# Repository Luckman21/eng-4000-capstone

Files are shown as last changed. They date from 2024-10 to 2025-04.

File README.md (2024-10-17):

# ENG-4000-Capstone
Our repo for ENG 4000 F2024 - W2025.  This is where we will store project documents, code and other resources related to our team.

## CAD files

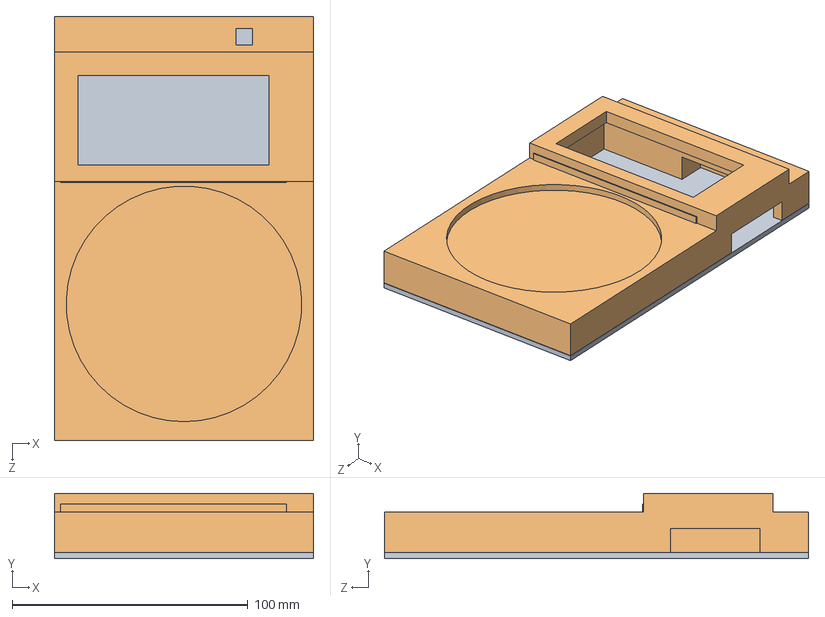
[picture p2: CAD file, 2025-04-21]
mech-design-team/Housings/Circuitry/CPSTN-A003 - ScaleHousing.SLDASM
110.0 x 27.7 x 180.0 mm
ScaleHousing
ScaleHousingLid

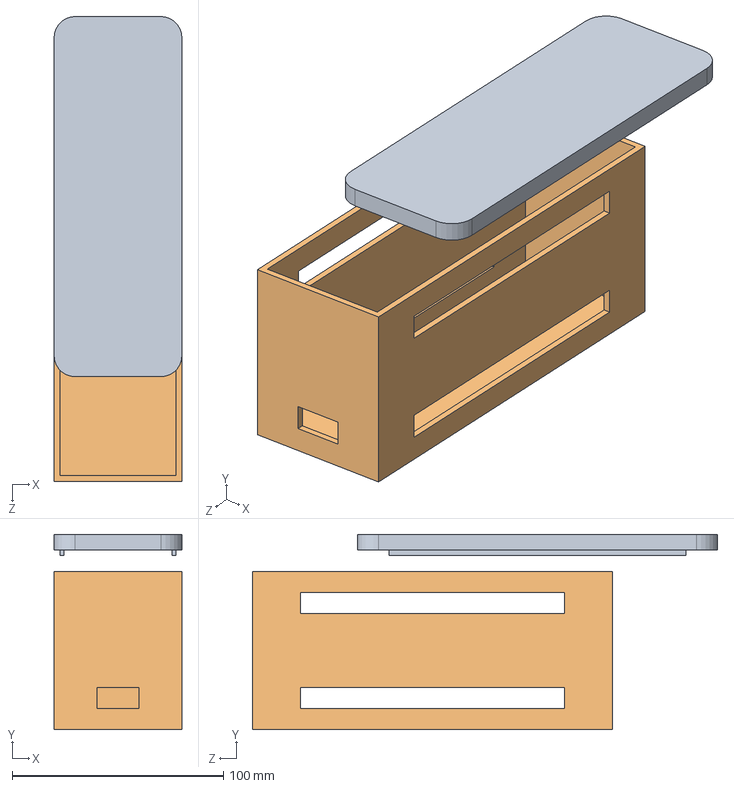
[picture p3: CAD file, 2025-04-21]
mech-design-team/Housings/Circuitry/CPSTN-A002 - Circuitry Housing.SLDASM
60.5 x 92.5 x 220.1 mm
BreadboardHousing
BreadboardHousingLid

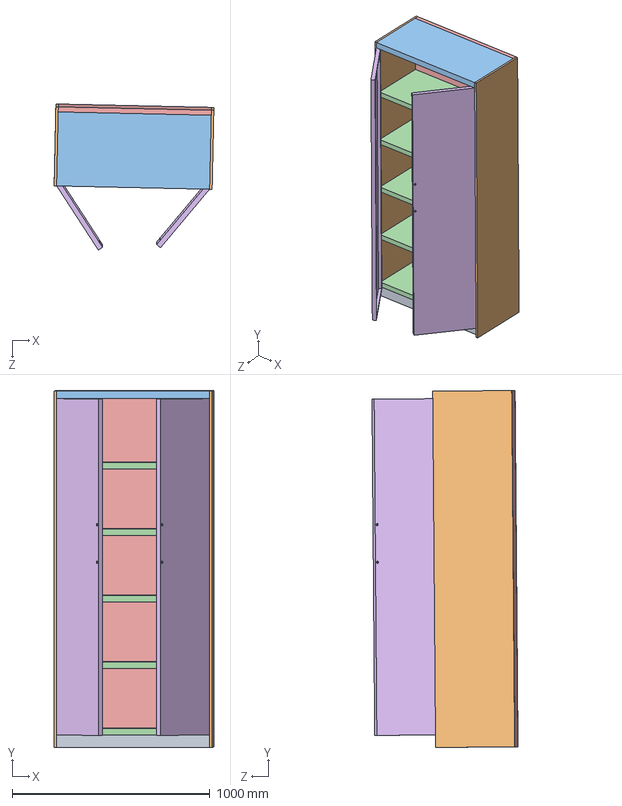
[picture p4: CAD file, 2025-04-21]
mech-design-team/Shelf/CPSTN-A001 - Shelving Unit Assembly.STEP
808.8 x 1806.6 x 739.3 mm
CPSTN-P001 - Shelf Base
CPSTN-P002 - Shelf Side Wall x 2
CPSTN-P003 - Shelf Roof
CPSTN-P004 - Cabinet Shelf x 5
CPSTN-P005 - Shelf Back Wall
CPSTN-P006 - Left Door
CPSTN-P007 - Right Door

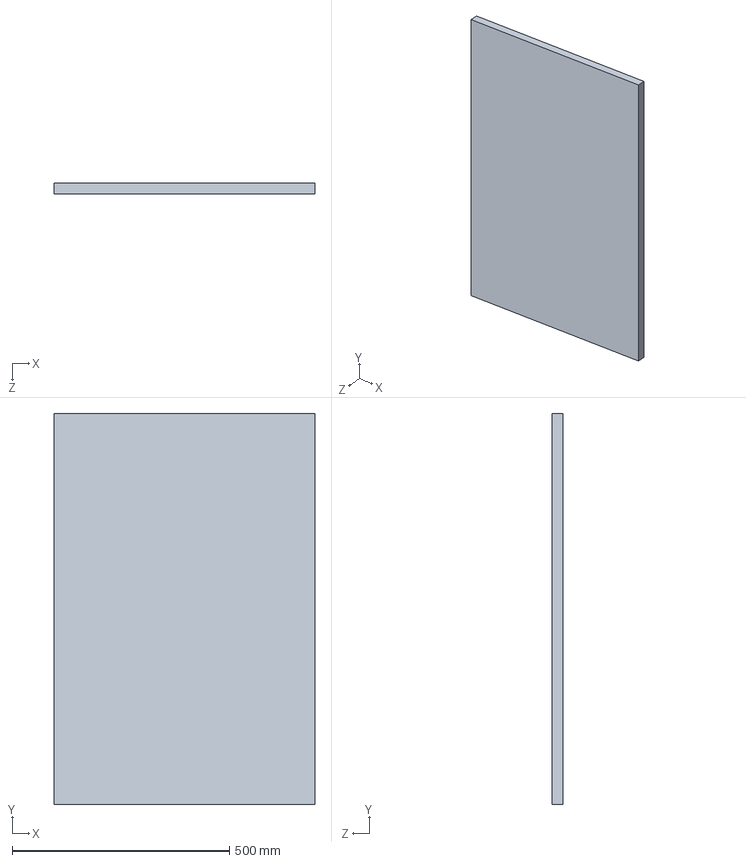
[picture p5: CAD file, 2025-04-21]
mech-design-team/Shelf/CPSTN-P005 - Shelf Back Wall.SLDPRT
599.4 x 899.2 x 25.4 mm

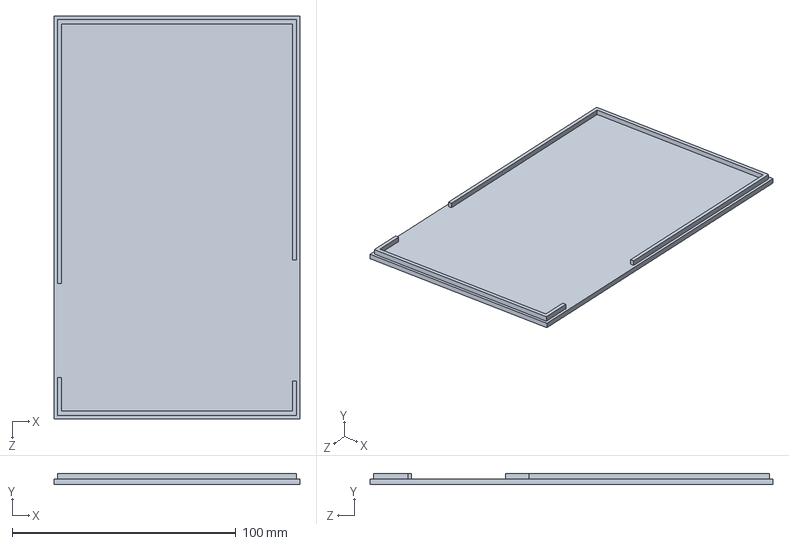
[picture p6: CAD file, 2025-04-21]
mech-design-team/Housings/Circuitry/ScaleHousingLid.SLDPRT
110.0 x 5.00 x 180.0 mm

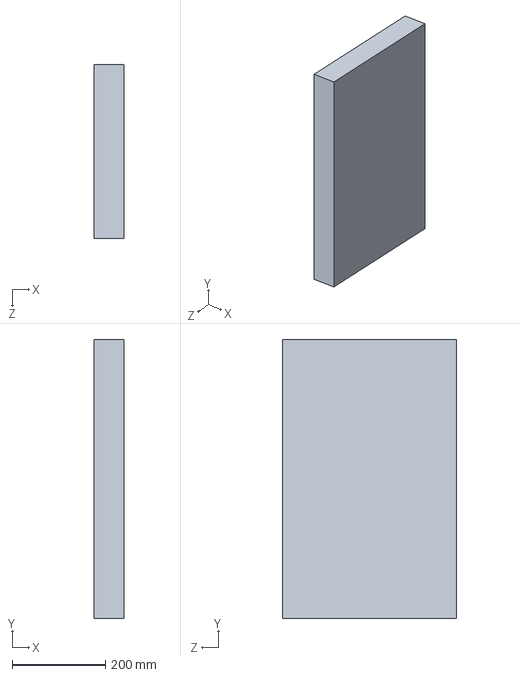
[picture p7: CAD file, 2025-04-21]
mech-design-team/Shelf/CPSTN-P001 - Shelf Base.SLDPRT
63.5 x 599.4 x 374.6 mm

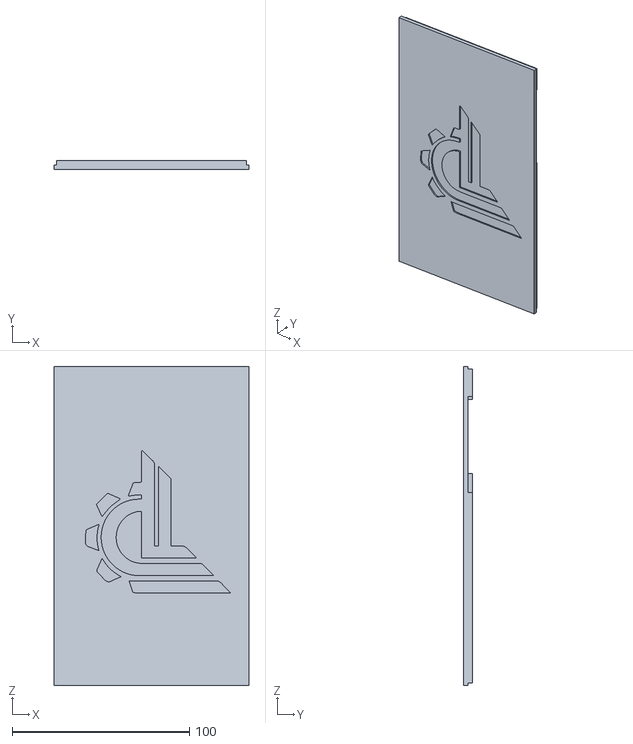
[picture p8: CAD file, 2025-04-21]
mech-design-team/Housings/Circuitry/ScaleHousingLid(2) v1.stl
110.0 x 5.00 x 180.0

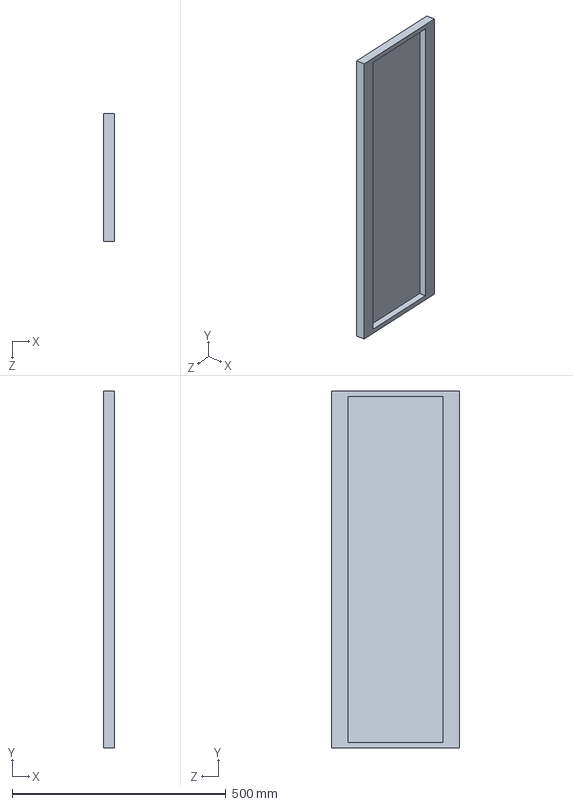
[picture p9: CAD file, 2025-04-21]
mech-design-team/Shelf/CPSTN-P006 - Left Door.SLDPRT
25.4 x 835.7 x 299.7 mm

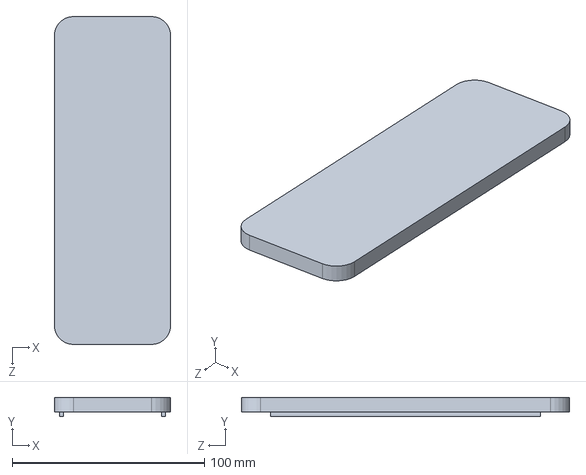
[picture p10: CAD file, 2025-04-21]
mech-design-team/Housings/Circuitry/BreadboardHousingLid.SLDPRT
60.5 x 10.0 x 170.5 mm

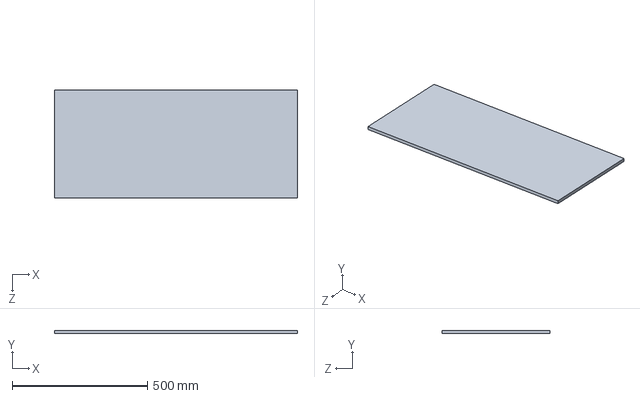
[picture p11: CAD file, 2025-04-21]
mech-design-team/Shelf/CPSTN-P002 - Shelf Side Wall.SLDPRT
899.2 x 12.7 x 400.1 mm

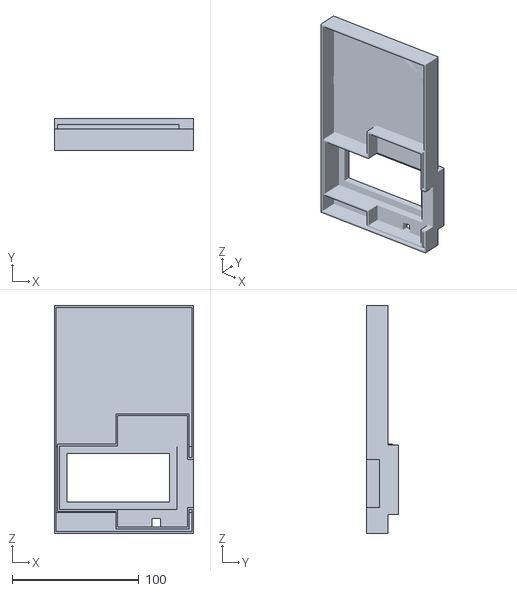
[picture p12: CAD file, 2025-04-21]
mech-design-team/Housings/Circuitry/ScaleHousing(2).STL
110.0 x 25.0 x 180.0

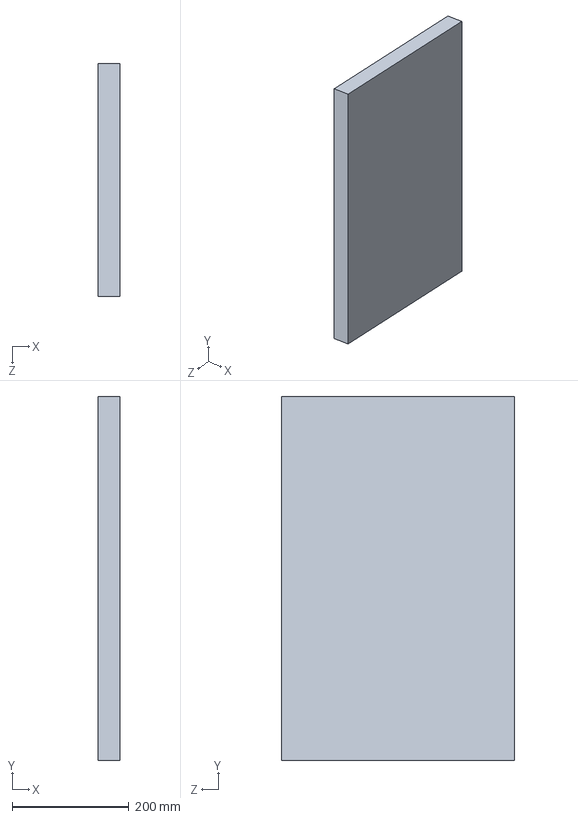
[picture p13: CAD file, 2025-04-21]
mech-design-team/Shelf/CPSTN-P003 - Shelf Roof.SLDPRT
38.1 x 624.8 x 400.0 mm

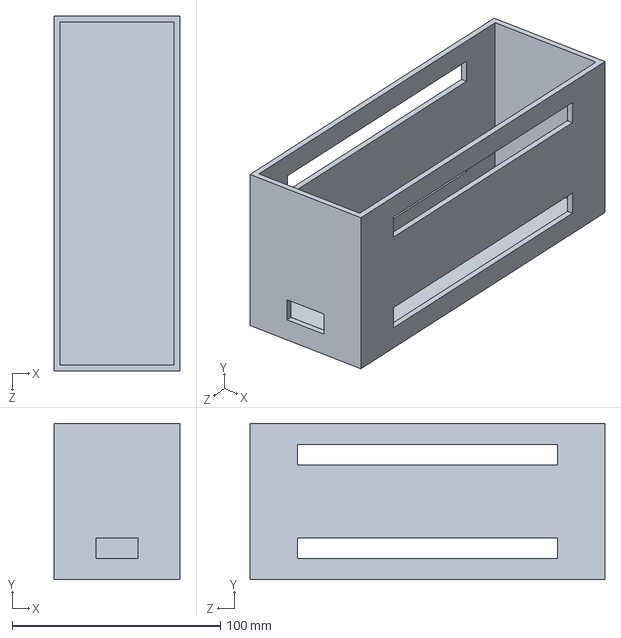
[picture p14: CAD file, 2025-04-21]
mech-design-team/Housings/Circuitry/BreadboardHousing.SLDPRT
60.5 x 75.0 x 170.5 mm

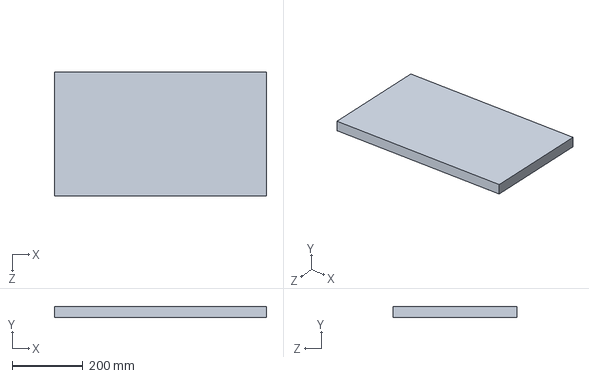
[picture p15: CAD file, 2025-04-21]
mech-design-team/Shelf/CPSTN-P004 - Cabinet Shelf.SLDPRT
599.4 x 31.8 x 349.2 mm

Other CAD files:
mech-design-team/Shelf/CPSTN-P007 - Right Door.SLDPRT
mech-design-team/Housings/Circuitry/BreadboardHousingLid(1).STL
mech-design-team/Housings/Circuitry/ScaleHousing.SLDPRT
mech-design-team/Housings/Circuitry/BreadboardHousing.STL
mech-design-team/Shelf/CPSTN-A001 - Shelving Unit Assembly.SLDASM

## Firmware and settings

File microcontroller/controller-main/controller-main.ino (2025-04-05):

#include <ArduinoMqttClient.h>
#include <WiFiNINA.h>
#include <Adafruit_Sensor.h>
#include <LiquidCrystal_I2C.h>
#include <DHT.h>
#include <DHT_U.h>
#include "HX711.h"

// YorkU network credentials
#define YORKU_SSID "AirYorkGUEST"
#define YORKU_PASS ""  // Should autoconnect to AirYorkGuest as MAC address is registered

// DHT11 important values
#define DHTPIN 6
#define DHTTYPE 11

// Calibration values
#define TEMP_CAL 23    // Adjusts the temperature reading for accuracy
#define HUMID_CAL 17   // Adjusts the humidity reading for accuracy
#define SCALE_CAL 417  // Adjusts the scale reading for accuracy

// Define HX711 pins
#define DOUT 2  // Data pin (DT)
#define CLK 3   // Clock pin (SCK)

#define BUTTON_PIN 4  // Button pin to tare the scale
#define SHELF_ID 1    // Unique to each board, set for each new unit

// For more information, check out https://freenove.com/fnk0079
// note:If lcd1602 uses PCF8574T, IIC's address is 0x27, or lcd1602 uses PCF8574AT, IIC's address is 0x3F.
LiquidCrystal_I2C lcd(0x27, 16, 2);

// Note: HX711 will require its own power source.  Make sure to connect all wires to a common ground to the Arduino
HX711 scale;  // Create HX711 object

char ssid[] = YORKU_SSID;  // network SSID (name)
char pass[] = YORKU_PASS;  // network password (used for WPA, or as a key for WEP)

WiFiClient wiFiClient;              // Create a wifiClient
MqttClient mqttClient(wiFiClient);  // Connect wifiClient to MqttClient

DHT_Unified dht(DHTPIN, DHTTYPE);  // Specify pin and sensor model

const char broker[] = "test.mosquitto.org";
int port = 1883;
const char topic_temp[] = "temp_value";
const char topic_humid[] = "humid_value";
const char topic_mass[] = "mass_value";

// Create an interval for sending messages (in milliseconds)
const long interval = 8000;
unsigned long prev_ms = 0;

// Values for scale measurements
long weight = 0;
long prev_weight = -1;  // Stores the value of the previous recorded weight, used to compare with the current reading

// Values for temp and humidity
float temp = 0;
float humid = 0;
float prev_temp = -1;
float prev_humid = -1;

// Create sensor events for both temp and humidity
sensors_event_t temp_event;
sensors_event_t humid_event;

// Initialize the device
void setup() {
  Serial.begin(57600);

  displayInit();  // Initialize the I2C LCD Display

  // set up DHT sensor
  dht.begin();
  sensor_t sensor;
  dht.temperature().getSensor(&sensor);

  // Boot Up Screen
  lcd.setCursor(0, 0);
  lcd.print("Pantheon3DP");
  lcd.setCursor(0, 1);
  lcd.print("Booting up");

  // Allow some time for the HX711 to stabilize
  for (int i = 0; i < 3; i++) {
    delay(300);
    lcd.print(".");
  }
  delay(100);

  // Initialize HX711
  scale.begin(DOUT, CLK);

  scaleReady();  // Determines if the HX711 module is ready

  scale.set_scale(SCALE_CAL);  // Set scale calibration factor

  // Perform tare (zero the scale)
  scale.tare();
  delay(2000);  // Wait for stabilization

  // Set the button pin as input with internal pull-up resistor
  pinMode(BUTTON_PIN, INPUT_PULLUP);

  wifiConnect();  // attempt to connect to Wifi network and to the MQTT broker
}

// The main body of the code, allows us to constantly run after setup
void loop() {
  // Maintain WiFi connection
  if (WiFi.status() != WL_CONNECTED) {
    Serial.println("WiFi connection lost. Reconnecting...");
    lcd.clear();
    lcd.setCursor(0, 0);
    lcd.print("NWork Offline.");
    lcd.setCursor(0, 1);
    lcd.print("Reconnecting:");
    wifiConnect();  // Reconnect WiFi if disconnected
  }

  // Maintain MQTT Broker connection
  if (!mqttClient.connected()) {
    Serial.println("MQTT broker connection lost. Reconnecting...");
    // Update LCD display
    lcd.clear();
    lcd.setCursor(0, 0);
    lcd.print("MQTT Offline.");
    lcd.setCursor(0, 1);
    lcd.print("Reconnecting:");
    connectMQTT();  // Attempt to reconnect to MQTT broker
  }
  mqttClient.poll();  // Sends MQTT keep alive, constantly called to keep connection alive

  if (digitalRead(BUTTON_PIN) == LOW) {
    tare();  // Tare the scale if button is pressed (pin is LOW)
  }

  // If the HX711 is ready, read the weight
  if (scale.is_ready()) {
    scaleMeasure();  // Read weight value from load cell and update value accordingly
  } else {
    Serial.println("HX711 not found.");
    lcd.clear();
    lcd.setCursor(0, 0);
    lcd.print("HX711 not");
    lcd.setCursor(0, 1);
    lcd.print("found.");
  }
  delay(500);

  readDHT11();  // Read from DHT11 sensor and update temp and humidity values accordingly
}

// Initialize Display
void displayInit() {
  // Set up I2C LCD Display
  Serial.println("Initializing display");
  if (!i2CAddrTest(0x27)) {
    lcd = LiquidCrystal_I2C(0x3F, 16, 2);
  }
  lcd.init();       // LCD driver initialization
  lcd.backlight();  // Open the backlight

  lcd.clear();
  Serial.println("Display initialized!");
}

// Determines if the HX711 module is ready
void scaleReady() {
  lcd.clear();
  // Check if HX711 is ready
  if (scale.is_ready()) {
    Serial.println("HX711 is ready!");
    lcd.setCursor(0, 0);
    lcd.print("HX711 is");
    lcd.setCursor(0, 1);
    lcd.print("ready!");
  } else {
    Serial.println("HX711 not found!");
    lcd.setCursor(0, 0);
    lcd.print("HX711 not");
    lcd.setCursor(0, 1);
    lcd.print("found.");
  }
}

// Connects to the specified WiFi network and establishes a connection to the MQTT broker
void wifiConnect() {
  // attempt to connect to Wifi network
  Serial.print("Attempting to connect to WPA SSID: ");
  Serial.println(ssid);

  // Print setup info to LCD
  lcd.clear();
  lcd.setCursor(0, 0);
  lcd.print("Connect to WPA:");
  lcd.setCursor(0, 1);
  lcd.print(ssid);

  while (WiFi.begin(ssid, pass) != WL_CONNECTED) {
    // failed, retry
    Serial.print(".");
    delay(5000);
  }
  Serial.println("Connected to network.\n");
  Serial.println("Attempting to connect to the MQTT broker: ");
  Serial.println(broker);

  // Update LCD display
  lcd.clear();
  lcd.setCursor(0, 0);
  lcd.print("NWork Connected.");
  lcd.setCursor(0, 1);
  lcd.print("Connect to MQTT:");

  connectMQTT();  // Connect to the MQTT broker
}

// Attempts to reconnect to the MQTT broker if it goes offline
void connectMQTT() {
  // Try to reconnect to the MQTT broker if the connection is lost
  Serial.println("Attempting to reconnect to MQTT broker...");
  
  // Try connecting to the MQTT broker
  if (!mqttClient.connect(broker, port)) {
    Serial.print("MQTT connection failed\nError Code = ");
    Serial.println(mqttClient.connectError());  // Prints the error code for debugging
    while (1)
      ;  // Keep trying until connection is successful
  }

  Serial.println("Connected to MQTT broker.\n");

  // Update LCD Display
  lcd.clear();
  lcd.setCursor(0, 0);
  lcd.print("Connected to ");
  lcd.setCursor(0, 1);
  lcd.print("MQTT Broker!");
}

// Used to test the address of the display to ensure it exists
bool i2CAddrTest(uint8_t addr) {
  Wire.begin();
  Wire.beginTransmission(addr);
  if (Wire.endTransmission() == 0) {
    return true;
  }
  return false;
}

// Print the weight to the top row of the display
void printMass(long weight) {
  lcd.setCursor(0, 0);
  lcd.print("Mass: ");
  lcd.print(weight);
  lcd.print("g");
}

// Print the temp and humidity to the bottom row of the display
void printDHT(float temp, float humid) {
  lcd.setCursor(0, 1);
  lcd.print("T:");
  lcd.print(temp, 1);
  lcd.print("C  H:");
  lcd.print(humid, 1);
  lcd.print("%");
}

// Clear the display and update with mass, temp and humidity
void updateDisplay(long weight, float temp, float humid) {
  lcd.clear();
  printMass(weight);
  printDHT(temp + TEMP_CAL, humid + HUMID_CAL);
}

// Reads data from the DHT11 Temp and Humid sensor, publishes to the MQTT broker
void readDHT11() {
  dht.temperature().getEvent(&temp_event);
  dht.humidity().getEvent(&humid_event);

  temp = temp_event.temperature;
  humid = humid_event.relative_humidity;

  if (prev_temp != temp) {
    prev_temp = temp;

    Serial.print("Send temp to topic_temp: ");
    Serial.println(topic_temp);
    Serial.println(temp + TEMP_CAL);

    // Send message, using print to send message contents
    mqttClient.beginMessage(topic_temp);
    mqttClient.print(String(SHELF_ID) + "|" + String(temp + TEMP_CAL));
    mqttClient.endMessage();

    updateDisplay(weight, temp, humid);
  }

  if (prev_humid != humid) {
    prev_humid = humid;

    Serial.print("Send humid to topic_humid: ");
    Serial.println(topic_humid);
    Serial.println(humid + HUMID_CAL);

    // Send message, using print to send message contents
    mqttClient.beginMessage(topic_humid);
    mqttClient.print(String(SHELF_ID) + "|" + String(humid + HUMID_CAL));
    mqttClient.endMessage();

    updateDisplay(weight, temp, humid);
  }
}

// Tares the scale reading
void tare() {
  Serial.println("Button pressed! Taring scale...");

  // Update the LCD with Tare sequence
  lcd.clear();
  printMass(weight);
  lcd.setCursor(0, 1);
  lcd.print("Taring");
  scale.tare();  // Tare the scale when the button is pressed

  // Debounce delay (prevents multiple taring actions)
  for (int i = 0; i < 3; i++) {
    lcd.print(".");
    delay(160);
  }
  updateDisplay(weight, temp, humid);
}

// Performs the scale measruement and outputs to MQTT and the serial monitor
void scaleMeasure() {
  // Get the average of 10 readings from the HX711
  weight = scale.get_units(10);  // Average of 10 readings

  // Print the weight to Serial Monitor for debugging
  Serial.print("Weight: ");
  Serial.println(weight);

  if (prev_weight != weight) {
    prev_weight = weight;

    updateDisplay(weight, temp, humid);

    // Update weight value in application via MQTT
    mqttClient.beginMessage(topic_mass);
    mqttClient.print(String(SHELF_ID) + "|" + String(weight));
    mqttClient.endMessage();
  }
}

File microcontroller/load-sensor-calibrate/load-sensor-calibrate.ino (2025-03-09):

#include "HX711.h"

// Define HX711 pins
#define DOUT 2   // Data pin (DT)
#define CLK 3    // Clock pin (SCK)
#define BUTTON_PIN 4  // Button pin to tare the scale

// Note: HX711 will require its own power source.  Make sure to connect all wires to a common ground to the Arduino

// Create HX711 object
HX711 scale;

void setup() {
  Serial.begin(57600);
  delay(1000);  // Allow some time for the HX711 to stabilize

  // Initialize HX711
  scale.begin(DOUT, CLK);

  // Check if HX711 is ready
  if (scale.is_ready()) {
    Serial.println("HX711 is ready!");
  } else {
    Serial.println("HX711 not found!");
  }

  // Set scale factor (adjust this based on your calibration)
  scale.set_scale(1000);  // This is just an example factor, adjust it

  // Perform tare (zero the scale)
  scale.tare();
  delay(2000);  // Wait for stabilization

  // Set the button pin as input with internal pull-up resistor
  pinMode(BUTTON_PIN, INPUT_PULLUP);
}

void loop() {
  // Check if button is pressed (active LOW)
  if (digitalRead(BUTTON_PIN) == LOW) {
    Serial.println("Button pressed! Taring scale...");
    scale.tare();  // Tare the scale when the button is pressed
    delay(500);  // Debounce delay (prevents multiple taring actions)
  }

  // If the HX711 is ready, read the weight
  if (scale.is_ready()) {
    // Get the average of 10 readings from the HX711
    long weight = scale.get_units(10);  // Average of 10 readings

    // Print the weight to Serial Monitor for debugging
    Serial.print("Weight: ");
    Serial.println(weight);
  } else {
    Serial.println("HX711 not found.");
  }

  delay(1000);  // Wait 1 second before the next reading
}

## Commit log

2024-11-05 User Table VS User Type Table comment fix Minor fix with the comments to assign the correct names to the comment headings, as they were switched previously.
2024-11-05 PR Changes V1 Based on Feedback Made the following requested changes to the PR after receiving feedback: - Removed setter methods for the shelf (data will be updated by sensors) - Added comments besi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
2024-11-21 Create listener.py V0.5
    Created a semi-skeleton of the listener / poller used to detect when materials fall below a threshold value of 50g in mass.
    Will need to figure out how to pass the instance of the materials table to the function, as well as to confirm the decision to use a poll instead of an event listener.
2024-11-22 Poll for DB change in materials
    After discussion with Nick, Luca and Paras, we came up with the following solution:
    - set up a listener to check when the materials in the DB get updated
    - Only poll when this listener is triggered
    This should reduce BW of having only one check every time stock changes / is added / is removed, and should account for aborted prints since those need to be updated to the DB manually and will incur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
2024-11-22 Merge edittable branch into SCRUM-19
    Merged changes from edittable branch so I could test the listener (since the current changes on the edittable branch allow you to modify the mass of the material).
2024-11-23 Listener V1 Listener in main is now triggered upon updating the Material table, however errors arise upon calling the async function to handle the trigger.
2024-11-23 Complete Listener V1
    Completed the listener function. A listener class contains all the required elements for the computation (polling function, a function to handle the listener trigger, session creation).
    The main function sets up the listener on startup, and triggers every time the Material table is updated.
2024-11-23 Remove Debug Print Statements from Listener
    Removed the debug print statements from listener.py.
2025-01-07 Create constants class
    Created a class for global constants for our backend. This should reduce code duplication and ensure parity across the backend, in case any of these values should change in the future.
2025-01-09 Complete Material unit test class
    Completed the unit test class for Material. It tests several aspects, like the setter methods, getAll and checks for different types of errors like invalid mass.
2025-01-09 Complete MaterialType unit test class
    Completed the unit test class for MaterialType. This test takes into consideration proper naming conventions, getAll and setters.
2025-01-09 Update Shelf tests
    Modified the Shelf class to properly raise exceptions when temperature or humidity is too low / high. Modified the tests so they function correctly. TODO: Resolve error when test_invalid_input_types test is run, the typeError exception is not raised and should be.
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2025-01-11 Couple of tests + test fixes
2025-01-11 added variable url links for easy switching (before we merge the constant class)
2025-01-13 Backend fix for material_type_id failure
2025-01-13 Frontend fix for material_type_id failure + integration test
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2025-01-16 Updated branch
    updated the branch to ensure it had the current main branch. However, the database file is still not able to open even though it connects to the testing URL.
2025-01-16 Deleteing a table isn't ideal in a test case. Rest looks good tho
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2025-01-19 Changed levenshtein distance for material types to 1. (IE one character typo of leniency)
2025-01-19 test case fixes
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2025-01-20 Try to fix driver issue
2025-01-20 Try to fix driver issue II
2025-01-20 Create DHT11 Sensor Calibration
    A sensor test and calibration class for the DHT11 Temperature and Humidity sensor. Displays the current temperature and humidity every 2 seconds in the Serial Monitor within the Arduino IDE.
2025-01-20 Microcontroller Connection V0.5
    Currently working on setting up the connection using MQTT protocol. The current code sets up the sensors and pins, tries to connect to the network, then a broker.
2025-01-20 Configure webapp to receive info over MQTT
    Set up an initial draft script that allows the webapp to connect to the MQTT topic set up by the Arduino board. Currently testing.
2025-01-20 Receive data from Arduino via MQTT
    Set up the listener on startup to connect to the port and broker, which allows the data to be sent from the Arduino to the database. Next steps will be to update the shelf values using this data.
2025-01-20 Fixed issues with connection to MQTT Broker
    Fixed some issues with connection to the MQTT broker. Renamed the broker to the correct destination (mosquitto), updated the error log code to correctly print the errors, and created a new sensor event to read temperature and humidity correctly. Sensors will still need to be calibrated.
2025-01-21 Allow Arduino to upload data independently
    Allows the Arduino to continue without waiting for the serial monitor to connect. This means that, with power, the Arduino will independently begin recording data and publishing once connected to the internet and a connection is established to a broker.
2025-01-21 Focus Extreme Values For Shelf
    Specified a shorter range of potential values for the shelf's temperature. The DHT11 sensor being used to record temperature and humidity has the following possible ranges:
    - Temperature: 0C to 50C +/- 2C
    - Humidity: 20% to 80% +/- 5%
    All tests pass, so this should not break any of the testcases.
2025-01-23 Add & Delete Material Type
    Add & Delete Material Type works. still debugging the edit button
2025-01-24 Remove autocomplete because it is not necessary for material type since each name is unique (so the edit is just a rebrand pretty much)
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2025-02-04 finished login and fixed material type bug also made some ui tweaks
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2025-02-12 fingers crossed this is fixed
2025-02-12 fingers crossed this is fixed II
2025-02-12 Fix failing test (edit material)
2025-02-12 Edit button is timing out. Going to up the waittime to see if that does the trick
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2025-02-21 Arduino DHT11 Sensor Calibration
    Calibrated the Arduino DHT11 sensor, which records temperature and humidity. Used the Govee Smart Thermo-Hygrometer as my baseline to calibrate with. After calibration, readings have been consistentl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
    Added the calibration values to both calibration ino files.
2025-02-22 Not a fan of how the email came out. Revert to link
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2025-03-01 Fixed MaterialType Table
    The table got nuked so I had to fix it
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2025-03-03 Create Load Cell and HX711 Calibration
    Initial calibration code to test functions such as reading from the scale, and taring the value with a button.
    Note: HX711 module requires its own power source, or readings will be inaccurate.
    Also note, despite different power sources, connect all grounds to one common ground, the Arduino ground pin.
    TODO: Adjust scale readings to calibrate scale for measurement in grams.
2025-03-04 Update controller-main for Mass Updates
    Add functionality to have the Arduino send scale readings via MQTT.
    The scale checks whether the value is different from the previous value measured. If so, the scale pushes the data to the new topic_mass.
    On the application side, we will need to create a buffer of size 1 to store the most recent mass reading, so when the backend controller method is signaled, it passes over the current mass value.
2025-03-04 Configure Webapp to Receive Scale Measurements via MQTT
    Set up an initial draft script that allows the webapp to connect to the MQTT mass topic set up by the Arduino board. Currently testing.
2025-03-05 MQTT Unit Tests (In Progress)
    Current progress of MQTT testing, Luca will take a look while I sort out issues pertaining my connection to the DB with psycopg library.
2025-03-09 Add I2C LCD Display to Main
    Added functionality for the I2C LCD display to our main driver code. The LCD display shows bootup steps, then displays the mass, as well as temperature and humidity readings.
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2025-03-09 Add Shelf ID to MQTT Payloads
    Added the shelf ID to the payloads being sent from the MC to the MQTT broker. The shelf ID will now be hardcoded on the MC side, so the backend can differentiate which shelf the information is being sent from. For users setting up their Arduino, they will need to modify the SHELF_ID macro near the top of the main class of the MC files.
    [controller-main.ino]
2025-03-09 Fix Invalid Test Case For Scale MQTT Unit Test Class
    Fixed an invalid test case for the MQTT scale test class. Previously, it would throw an error because the payload format changed. The test now passes with the requirements updated.
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2025-03-14 Fixed Export Buttons and Created Tests
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2025-03-18 Fixed Material Table test
    changed the material table order test to make sure it waits and checks the first two rows before loading everything in
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2025-03-26 Reconnect to WiFi and MQTT Broker
    Added logic to the microcontroller to reconnect to WiFi network and the MQTT broker in the event either are disconnected. This should help improve the uptime of the board, since the WiFi connection at York can be unstable at times.
    [controller-main.ino]
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
